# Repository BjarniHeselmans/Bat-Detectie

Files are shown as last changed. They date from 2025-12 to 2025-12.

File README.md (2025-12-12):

# Vleermuizen en Spouwmuren – ESPHome Sensor Node



## 1. Inleiding — Waarom bestaat dit project?

Dit project maakt deel uit van het BatSense-onderzoek rond vleermuizen en spouwmuren binnen de opleiding Elektronica-ICT aan Hogeschool PXL.  
Vleermuizen maken gebruik van spouwmuren als leef- en verplaatsingsruimte. Om dat gebruik beter te begrijpen, is betrouwbare monitoring van de omgevingscondities (zoals temperatuur en luchtvochtigheid) in die spouwmuren nodig.

Binnen het grotere BatSenseEmbedded-project werken meerdere deelteams samen aan een modulair systeem met verschillende nodes en een centrale verwerking.  
Deze repository focust op één specifieke node: een compacte, batterijgevoede sensormodule op basis van een ESP32-S2 (S2 Mini) en ESPHome, die via Wi‑Fi meetdata uit de spouwmuur doorstuurt naar het centrale systeem, gevormd door Home assistant.

---

## 2. Doelstelling — Wat moest er op het einde werken?

Het doel van dit deelproject is een werkende, reproduceerbare sensor node op te leveren die:

- temperatuur en relatieve luchtvochtigheid in een spouwmuur kan meten met een SHT30/SHT3X-sensor;
- autonoom op batterij kan functioneren, met deep-sleep om energie te besparen;
- via ESPHome elke sensor logisch aan de ESP32-S2 koppelt;
- de gemeten waarden via Wi‑Fi doorstuurt naar een centraal systeem (bv. Home Assistant of een backend uit BatSenseEmbedded);
- voldoende gedocumenteerd is (hardware + firmware) zodat een andere student de node opnieuw kan bouwen en integreren in het BatSense-systeem.
- De node moet aantoonbaar meetdata leveren die in het centrale systeem zichtbaar en logbaar is.

---

## 3. Materialen & Methoden — Hoe is het gebouwd?

### 3.1 Hardware

De sensor node bestaat uit:

- **Microcontroller:**  
  ESP32-S2 Mini (S2 Mini) met geïntegreerde Wi‑Fi.
- **Sensor:**  
  SHT30/SHT3X voor temperatuur- en relatieve luchtvochtigheid (I²C-communicatie).
- **Voeding:**  
  PowerBoost 500 Charger voor batterijvoeding en laadfunctionaliteit.
- **Overige:**  
  Bekabeling, connectoren en een behuizing/opstelling geschikt voor plaatsing in een spouwmuur.

- **[Research.md](./Docs/Research.md)** – hardwareopzet en keuzes
- **[board_controle.md](./Docs/Board_controle.md)** – basiscontroles van de S2 Mini
- **[sensor_kabels.md](./Docs/SensorKabels.md)** – sensorbekabeling en aanpassingen
- **[s2mini_flashen.md](./Docs/S2mini_flashen.md)** – stappen om de S2 Mini te flashen met ESPHome

De bekabeling, pinout en fysieke opstelling worden beschreven in de documenten in **[Docs/](./Docs/)**:

### 3.2 Firmware & Software (ESPHome & Home Assistant)

De volledige firmware op de sensornodes wordt opgebouwd met **ESPHome** en gekoppeld aan **Home Assistant** als centraal verwerkings- en visualisatieplatform.  
Belangrijkste elementen:

- **Configuratiebestand (ESPHome):**  
  [Scripts/base.yaml](./Scripts/base.yaml)
- **Sensorconfiguratie:**  
  Declaratie van de SHT3X-sensor via I²C, inclusief meetfrequentie.
- **Energiebeheer:**  
  Deep-sleep-configuratie om de node slechts periodiek te laten meten en verzenden.
- **Wi-Fi-configuratie:**  
  In `base.yaml` worden SSID en wachtwoord ingesteld zodat de node automatisch verbinding maakt met het netwerk.
- **Datadoorsturing:**  
  ESPHome publiceert de meetwaarden als netwerkentiteiten.
- **Home Assistant-integratie:**  
  Home Assistant detecteert de ESPHome-nodes automatisch, registreert alle sensoren als entiteiten, logt de meetwaarden continu en visualiseert deze via dashboards en grafieken.
- **Dataopslag & historiek:**  
  Meetdata blijft persistent bewaard in Home Assistant en blijft beschikbaar na een herstart.

### 3.3 Architectuur en datastroom

De datastroom voor deze node verloopt als volgt:

1. De node wordt gevoed door de batterij via de PowerBoost 500 Charger.
2. De ESP32-S2 wordt wakker uit deep-sleep.
3. ESPHome leest de SHT30/SHT3X-sensor uit via I²C (temperatuur en luchtvochtigheid).
4. De ESP32-S2 maakt verbinding met het Wi‑Fi-netwerk.
5. ESPHome stuurt de gemeten waarden via Wi‑Fi naar het centrale systeem (bv. Home Assistant of een server binnen BatSenseEmbedded).
6. Home Assistant ontvangt de data, slaat deze persistent op, en visualiseert de meetwaarden via dashboards en grafieken.
7. De data kan vanuit Home Assistant verder worden geëxporteerd (CSV/Excel).

Deze node is daarmee één van de sensoren in het grotere BatSenseEmbedded-ecosysteem, waar meerdere nodes en servers samenwerken.

---

## 4. Resultaten — Wat werkt effectief?

De volgende resultaten werden bereikt met deze sensor node:

- **Werkende hardwaremodule:**  
  De combinatie van S2 Mini, PowerBoost 500 Charger en SHT30/SHT3X levert een stabiel systeem op dat in een spouwmuur kan geplaatst worden.
- **Stabiele omgevingsmetingen:**  
  Temperatuur- en vochtigheidswaarden worden betrouwbaar uitgelezen via ESPHome.
- **Wi‑Fi-communicatie:**  
  De node maakt verbinding met het geconfigureerde Wi‑Fi-netwerk en publiceert de sensorwaarden als entiteiten.
- **Integratie met centraal systeem:**  
  De data kan worden ingelezen en gelogd door een hoger niveau platform (bijvoorbeeld Home Assistant of een centrale server binnen BatSenseEmbedded).

Het aantal werkende modules, testduur en stabiliteitstesten hangen af van de concrete metingen en opstellingen die in de loop van het project zijn uitgevoerd. Deze kunnen aangevuld worden met grafieken, logs en screenshots in de documentatie en in de centrale projectrapportage.

---

## 5. Besluit — Wat hebben we geleerd?

Uit dit deelproject rond de ESPHome sensor node kwamen de volgende inzichten naar voren:

- **Energiebeheer is cruciaal:**  
  Deep-sleep en meetinterval hebben een grote impact op de batterijduur. Het juist instellen hiervan is essentieel voor langdurige metingen in spouwmuren.
- **Omgevingsinvloeden:**  
  Vocht en condensatie vormen een risico voor de hardware. Het ontwerp van de behuizing en de plaatsing van de sensor zijn belangrijk voor de betrouwbaarheid.
- **Wi‑Fi-bereik en stabiliteit:**  
  In of rond een spouwmuur is het Wi‑Fi-signaal niet altijd optimaal. Dit moet meegenomen worden in de plaatsing van nodes en de keuze van access points.
- **Modulariteit binnen BatSenseEmbedded:**  
  Door ESPHome te gebruiken en de node duidelijk te documenteren, kan deze sensor eenvoudig geïntegreerd worden in de centrale BatSenseEmbedded-architectuur en door andere studenten worden nagebouwd of uitgebreid.

Deze node levert zo een concrete, technische bouwsteen voor het bredere vleermuis- en spouwmurenonderzoek, en illustreert hoe een robuuste, batterijgevoede IoT-sensorknoop ontworpen en gedocumenteerd kan worden.

---

## Projectstructuur (overzicht)

Docs/
Research.md
01_board_controle.md
02_sensor_kabels.md
03_s2mini_flashen.md
Attachments/
... (screenshots en foto’s)

Scripts/
HTSensor.yaml

text

- **[Docs/](./Docs/)** bevat alle documentatie rond hardware, tests en opbouw.
- **[Scripts/](./Scripts)** bevat de ESPHome-configuratie waarmee de sensoren gekoppeld en via Wi‑Fi doorgestuurd worden.
- **[firmware/](./firmware/)** bevat dummy sensor logica.

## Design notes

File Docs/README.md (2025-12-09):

Deze map bevat alle documentatie die is opgesteld tijdens het **Bat Detectie**-project.  
Hieronder volgt een overzicht van de bestanden en hun inhoud.

---

## Documenten

### 1. [Research.md](./Research.md)
**Onderwerp:** Hardware overzicht en functionaliteit.  
**Inhoud:**  
- Beschrijving van de **S2 Mini**, **PowerBoost 500 Charger** en **SHT30-sensor**.  
- Functionele uitleg van voeding, opladen en datalogging.  
- Aansluitingen en pinout details.  
- Toepassingen, tips en referenties naar datasheets en documentatie.

---

### 2. [Board_controle.md](./Board_controle.md)
**Onderwerp:** Controle van de S2 Mini-boardjes.  
**Inhoud:**  
- Testen van de boardjes via **Arduino IDE** en seriële monitor.  
- Identificatie van werkende en defecte boardjes.  
- Nummering en registratie voor verdere verwerking.  
- Screenshot van de seriële monitoruitvoer: **[./Attachments/serial_monitor_output.png](./Attachments/serial_monitor_output.png)**.

---

### 3. [Sensor_kabels.md](./SensorKabels.md)
**Onderwerp:** Verkorten en aansluiten van SHT3X-sensorbekabeling.  
**Inhoud:**  
- Controle op schade en waterschade.  
- Verkorten van kabels tot 1 meter voor betrouwbare I²C-communicatie.  
- Correcte aansluiting volgens datasheet.  
- Foto van sensor met kabel: **[./Attachments/SensorCable.png](./Attachments/SensorCable.png)**.

---

### 4. [S2mini_flashen.md](./S2mini_flashen.md)
**Onderwerp:** Flashen van de S2 Mini met ESPHome.  
**Inhoud:**  
- Installatie van ESPHome via pip.  
- Flashen met `esphome run .` en testen via `esphome logs .`.  
- YAML-configuratie voor de sensor, Wi-Fi, deep sleep en logging.  
- Gemaakt in samenwerking met Alexander (junior onderzoeker).

---

### 5. [ErrorGuide.md](./ErrorGuide.md)
**Onderwerp:** Guide to fix the commen error to be unable to flash.  
**Inhoud:**  
- een step by step guide om de error te kunnen oplossen
- vervolgt met de mannier om de esp te flashen

---

### 6. [HWInstallationGuide.md](./HWInstallationGuide.md)
**Onderwerp:** Hardware assembly guide for the casing.  
**Inhoud:**  
- een step by step guide om de casing in elkaar te steken

---

## Bijlagen

- **Attachments/**  
  Bevat afbeeldingen ter ondersteuning van de documentatie:

---

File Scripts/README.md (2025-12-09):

# ESPHome Sensor Node – Gebruik en Flashen

Deze sectie legt uit hoe de ESPHome-configuratie voor de sensor node werkt
en hoe je de firmware flasht op de **S2 Mini (ESP32-S2)** binnen dit project.

---

## 1. Wat doet deze ESPHome-config?

De ESPHome-configuratie voor deze node zorgt ervoor dat de S2 Mini:

- verbinding maakt met Wi‑Fi;
- de **SHT30/SHT3X-sensor** via I²C uitleest;
- **temperatuur** en **luchtvochtigheid** als entiteiten beschikbaar maakt;
- (optioneel) **deep-sleep** gebruikt om batterij te besparen;
- OTA-updates en logging via ESPHome ondersteunt.

De belangrijkste configuratie staat in:

- `Scripts/device(NMR).yaml`

---

## 2. Bestanden en structuur

In deze repo:

- `Scripts/HTSensor.yaml`  
  ESPHome-configuratie voor de S2 Mini:
  - type bord (`esp32-s2` / S2 Mini)
  - Wi‑Fi-instellingen
  - SHT30/SHT3X-sensor (I²C)
  - logger, API, OTA, deep-sleep (indien geconfigureerd)

- `Docs/03_s2mini_flashen.md`  
  Stapsgewijze uitleg om de S2 Mini te flashen (achtergrond en screenshots).

---

## 3. Voorbereiding

1. **Benodigdheden**
   - S2 Mini (ESP32-S2)
   - SHT30/SHT3X-sensor correct aangesloten (zie `Docs/02_sensor_kabels.md`)
   - USB‑kabel naar je pc
   - Wi‑Fi-netwerk (SSID + wachtwoord)

2. **Software**
   - Python + `pip`
   - ESPHome installeren:
     ```
     pip install esphome
     ```
   - Optioneel: ESPHome Dashboard (via Home Assistant of standalone)

---

## 4. Wi‑Fi en sensorgegevens instellen

Open `Scripts/HTSensor.yaml` en controleer:

- **Wi‑Fi-instellingen**:
wifi:
ssid: "JOUW_SSID"
password: "JOUW_WACHTWOORD"

- **Sensorconfiguratie** (voorbeeld):
i2c:
sda: <GPIO_SDA>
scl: <GPIO_SCL>
scan: true

sensor:
- platform: sht3xd
temperature:
name: "Spouwmuur Temperature"
humidity:
name: "Spouwmuur Humidity"
address: 0x44
update_interval: 10s

Pas hier enkel aan wat in jouw opstelling afwijkt (SSID, wachtwoord, pinnen, namen).

---

## 5. Eerste keer flashen (via USB)

1. Verbind de S2 Mini via USB met je pc.
2. Ga in een terminal naar de projectmap:
cd Scripts

3. Flash de node met ESPHome:
esphome run HTSensor.yaml

4. Kies de juiste seriële poort wanneer ESPHome daarom vraagt.

ESPHome:
- compileert de firmware;
- uploadt ze naar de S2 Mini.

---

## 6. Logs bekijken en testen

Na het flashen kun je live logs bekijken:

esphome logs HTSensor.yaml

Controleer of:
- de node verbinding maakt met je Wi‑Fi;
- de SHT30/SHT3X-sensor waarden geeft;
- (indien ingesteld) deep-sleep correct werkt (node gaat slapen en wordt weer wakker).

---

## 7. OTA-updates (draadloos)

Na de eerste USB-flash kun je wijzigingen aan `HTSensor.yaml` draadloos uploaden:

esphome run HTSensor.yaml

ESPHome zoekt dan de node op je netwerk en doet een OTA-update.

---

## 8. Integratie in het BatSense-systeem

De sensoren die in `HTSensor.yaml` gedefinieerd zijn (bijv. `Spouwmuur Temperature`,
`Spouwmuur Humidity`) verschijnen als entiteiten in ESPHome / Home Assistant
of kunnen door de centrale BatSense-componenten uitgelezen worden volgens de
architectuur die in het teamproject is afgesproken.

---

## 9. Veelvoorkomende problemen

- **Node verschijnt niet op Wi‑Fi**  
  → Controleer SSID/wachtwoord in `HTSensor.yaml`.  
- **Geen sensorwaarden**  
  → Controleer I²C-pinnen en bekabeling (zie `Docs/02_sensor_kabels.md`).  
- **Geen logs**  
  → Controleer seriële poort of netwerk, probeer opnieuw:
    ```
    esphome logs HTSensor.yaml
    ```

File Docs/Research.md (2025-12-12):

# S2 Mini & PowerBoost 500 Charger & SHT30

Dit project combineert de **S2 Mini** microcontroller met de **Adafruit PowerBoost 500 Charger** en de **SHT30 temperatuur- en vochtigheidssensor** voor een compacte, draagbare oplossing die zowel voeding, opladen als omgevingsmeting ondersteunt.

## Componenten

- **S2 Mini**
  - ESP32-S2 gebaseerde microcontroller
  - Ondersteunt Wi-Fi
  - Klein formaat en laag energieverbruik

- **PowerBoost 500 Charger**
  - LiPo/Li-ion batterij lader
  - 5V boost converter tot max. 500mA
  - Micro-USB aansluiting voor opladen
  - Automatische overschakeling tussen USB- en batterijvoeding

- **SHT30**
  - Temperatuur- en luchtvochtigheidssensor
  - Meetbereik:
    - Temperatuur: -40 tot +125 °C (±0.2 °C nauwkeurigheid)
    - Vochtigheid: 0–100 %RH (±2 %RH nauwkeurigheid)
  - Communicatie via I²C
  - Lage stroomconsumptie, geschikt voor draagbare toepassingen

## Functionaliteit

- Voeding van de **S2 Mini** via een LiPo- of Li-ion batterij.
- Opladen van de batterij via micro-USB.
- 5V output van de PowerBoost voedt direct de S2 Mini.
- Metingen van temperatuur en luchtvochtigheid via de SHT30.
- Data kan via Wi-Fi worden doorgestuurd of lokaal verwerkt.
- Ideaal voor draagbare IoT-projecten en omgevingsmonitoring.

## Aansluitingen
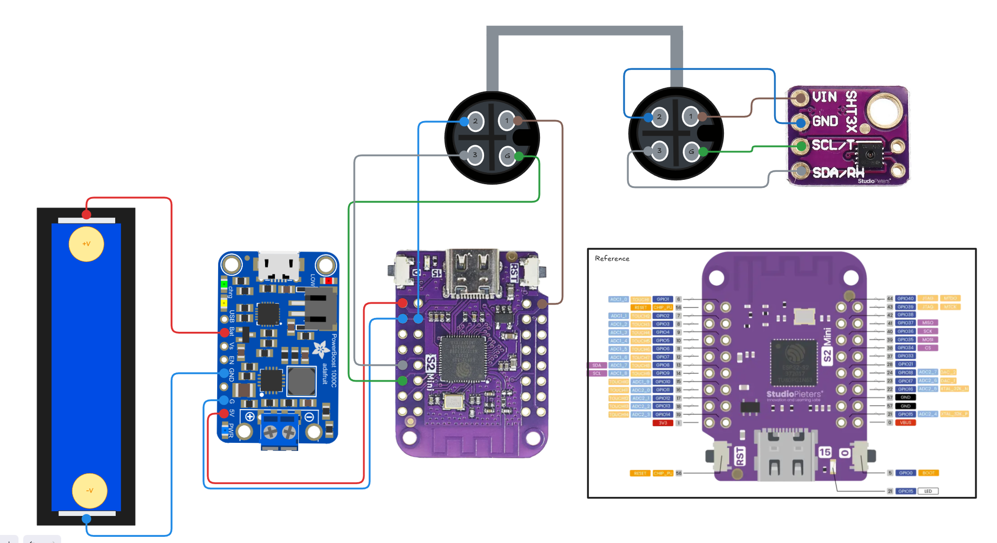
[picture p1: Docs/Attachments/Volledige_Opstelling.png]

1. **Batterij → PowerBoost**
   - Verbind een LiPo/Li-ion batterij met de JST-connector van de PowerBoost.

2. **PowerBoost → S2 Mini**
   - Sluit de **5V-uitgang** van de PowerBoost aan op de **5V/VBUS pin** van de S2 Mini.
   - Sluit **GND** van beide borden aan.

3. **SHT30 → S2 Mini**
   - **VCC** → 3.3V pin van de S2 Mini  
   - **GND** → GND van de S2 Mini  
   - **SDA** → GPIO 8 (SDA)  
   - **SCL** → GPIO 9 (SCL)  
   *(controleer de pinout van je S2 Mini, sommige boards gebruiken andere standaard I²C-pinnen)*

4. **Opladen**
   - Gebruik een micro-USB kabel op de PowerBoost om de batterij op te laden.
   - Het systeem kan tijdens het opladen blijven functioneren.

## Let op

- Zorg dat de aangesloten batterij correct gepolariseerd is (rode draad = +, zwarte draad = -).
- De PowerBoost levert max. 500mA; houd rekening met stroomverbruik van de S2 Mini, SHT30 en eventuele extra randapparatuur.
- De SHT30 werkt op 3.3V; sluit hem niet aan op 5V.
- Gebruik een geschikte LiPo- of Li-ion batterij (bij voorkeur ≥ 500mAh).

## Toepassingen

- Draagbare IoT-projecten
- Sensoren en datalogging
- Omgevingsmonitoring (temperatuur en luchtvochtigheid)
- Kleine robotica toepassingen
- Wearables

## Referenties

- [S2 Mini documentatie](https://www.wemos.cc/en/latest/s2/s2_mini.html)  
- [Adafruit PowerBoost 500 Charger](https://cdn-learn.adafruit.com/downloads/pdf/adafruit-powerboost-500-plus-charger.pdf)  
- [SHT30 Datasheet (Sensirion)](https://sensirion.com/media/documents/213E6A3B/63A5A569/Datasheet_SHT3x_DIS.pdf)
- [SHT3x module functionality(controllerstech)](https://controllerstech.com/interface-sht3x-with-arduino/)

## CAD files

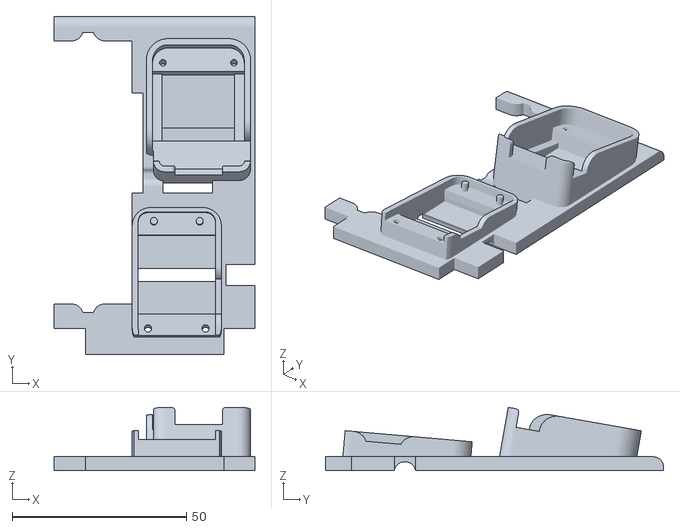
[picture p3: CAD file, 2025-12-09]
Docs/3D models/ScrewholderOBJ.obj
57.7 x 97.0 x 18.2

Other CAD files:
Docs/3D models/ScrewholderSTL.stl
Docs/3D models/Screwholder.3mf

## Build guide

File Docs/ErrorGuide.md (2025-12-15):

# ESPHome Installatiegids (zonder dependency-conflicten)

Deze handleiding legt uit hoe je ESPHome correct installeert in een aparte virtuele Python-omgeving zodat er geen conflicten ontstaan met andere pakketten zoals *mediapipe*.

---

## Waarom een virtuele omgeving?
Sommige pakketten vereisen **protobuf 4.x**, terwijl ESPHome **protobuf 5+** nodig heeft. Dit botst in één Python-installatie.  
Een virtuele omgeving voorkomt deze problemen.

---

# ESPHome installeren in een virtuele omgeving

## 1. Virtuele omgeving aanmaken
Maak een aparte map met een eigen Python-omgeving:

```bash
python -m venv esphome-env
```

---

## 2. Virtuele omgeving activeren

### **Windows**
```bash
esphome-env\Scripts\activate
```

Wanneer actief verschijnt `(esphome-env)` vóór je command prompt.

---

## 3. ESPHome installeren
Installeer ESPHome binnen deze omgeving:

```bash
pip install esphome
```

ESPHome kiest automatisch een geschikte protobuf-versie (5.x of 6.x).

---

# Projectstructuur

Plaats je ESPHome-configuratie (YAML-bestanden) in een normale gebruikersmap, bijvoorbeeld:

```
C:\Users\JouwNaam\Documents\ESPHome\
```

Ga daarna naar die map:

```bash
cd C:\Users\JouwNaam\Documents\ESPHome
```

---

# ESPHome gebruiken

## Firmware compileren en uploaden

```bash
esphome run device1.yaml
```

## Live logs bekijken

```bash
esphome log device1.yaml
```

---

# Verrificatie dat de sensor is geupload:



---

# Aanbevolen werkwijze

Gebruik **altijd** een virtuele omgeving voor ESPHome om dependency-conflicten te vermijden.

---

Veel succes!

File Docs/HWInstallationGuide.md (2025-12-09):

# Bottomcase install

## Step 1

Firstly be sure to check if all the required parts are found like in the image below. You should have 2 tiny screws for the ESP32, the 3D print to hold the parts, the lithium battery holder+battery management system+ESP32, another set of screws for the bms and finally the 4 big ones to screw in the lid to the enclosure.

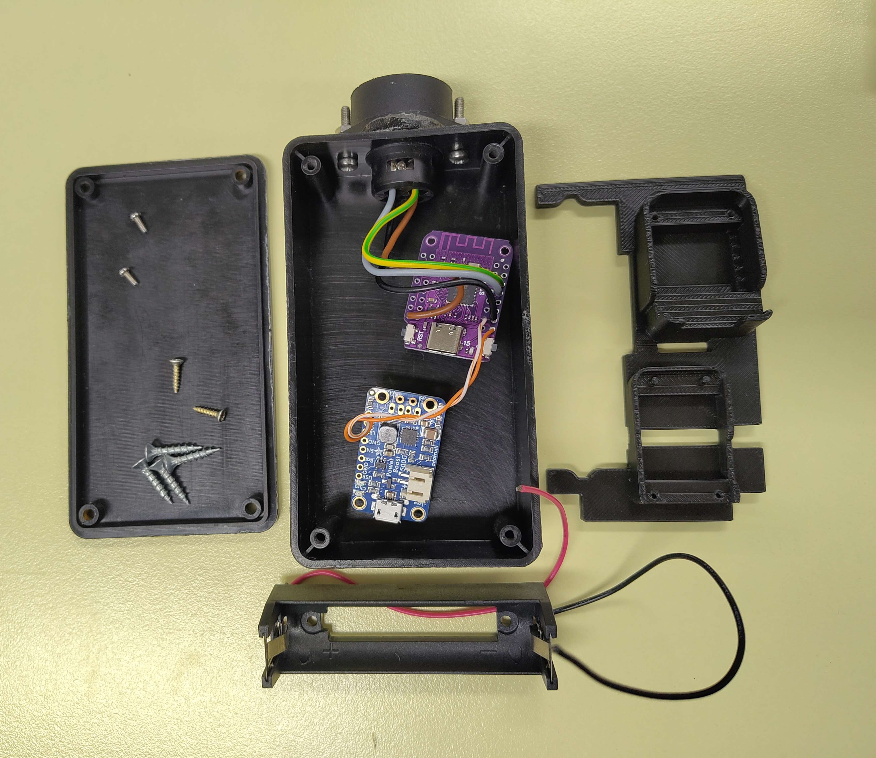
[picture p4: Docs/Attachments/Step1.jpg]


## Step 2

Now that you have confirmed that all components are included be sure to safely insert the battery holder inside of the 3D printed screwholder since it will be easier to mount it inside of the enclose this way.

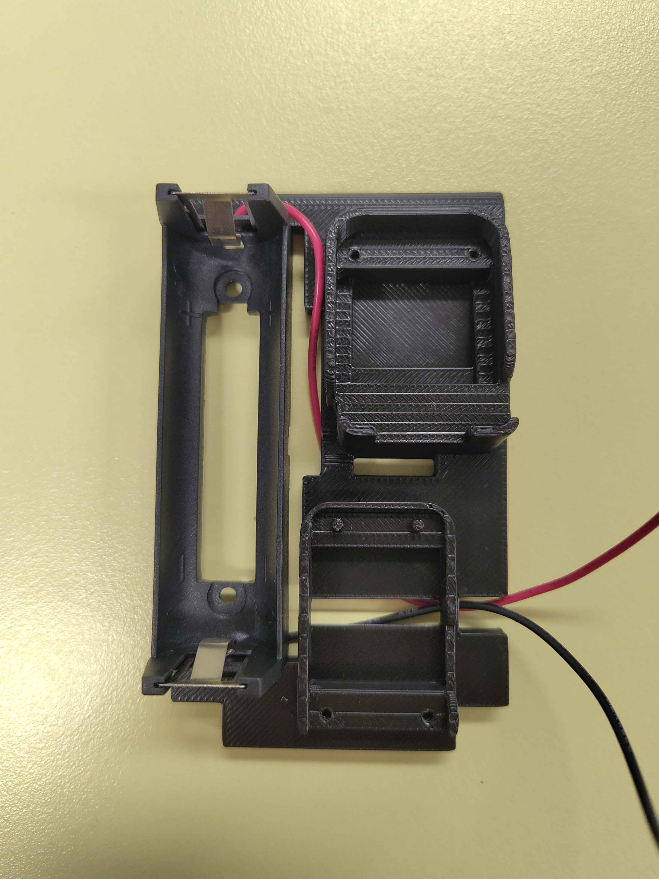
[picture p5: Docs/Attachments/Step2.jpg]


## Step 3

After that is done the screwholder can be safely slotted in making sure that the curved side is aimed to the top and that it looks like the image below. Then you can use the 4 tiny included screws to screw in the esp and the BMS system into the enclosure.

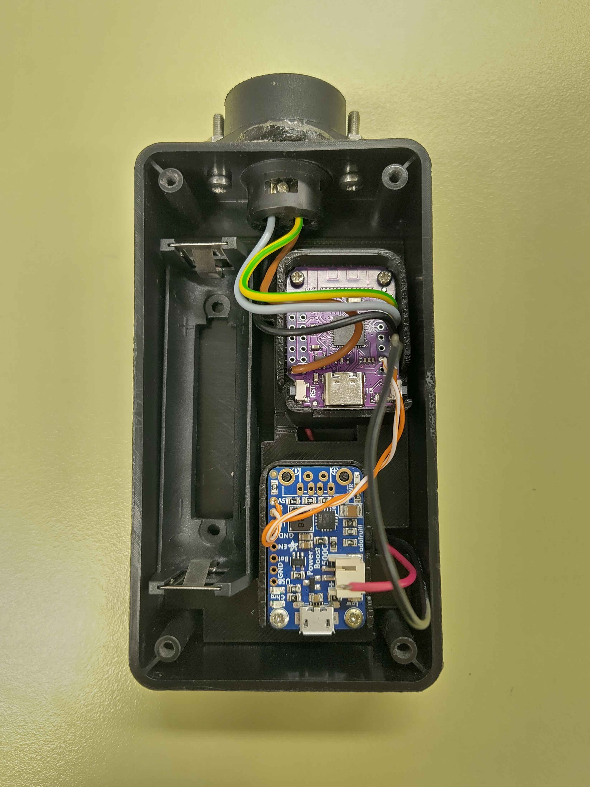
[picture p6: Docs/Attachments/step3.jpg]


## Step 4

Next the battery can be slotted into the enclosure making sure that the polarity is correct. This can be checked by aligning the + and minus sign as shown in the image below.

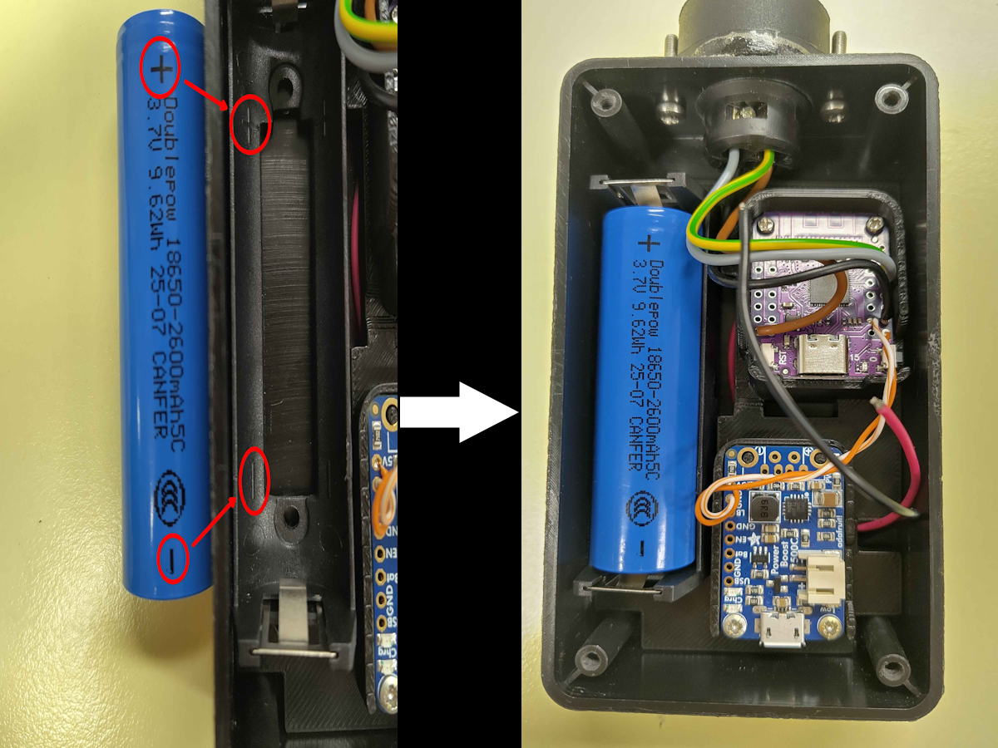
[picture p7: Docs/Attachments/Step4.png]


# Step 5

Now that everything for inside the case is installed the lid can be placed on top and screwed in with the biggest 4 screws the sensor kit is now fully assembled!

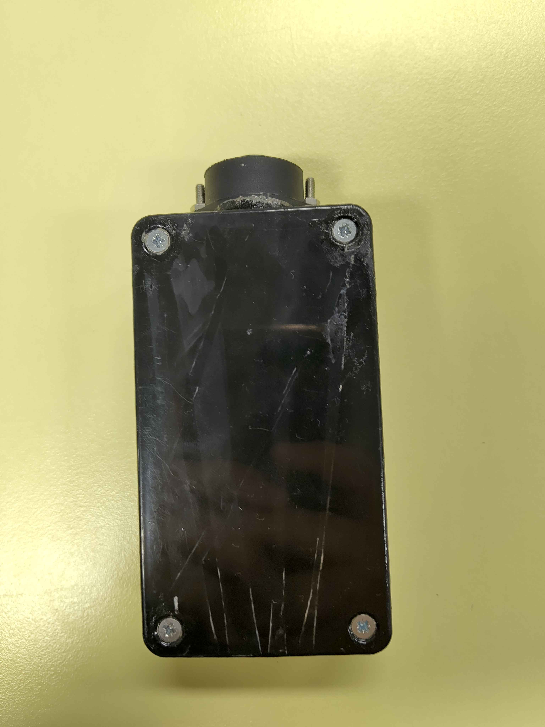
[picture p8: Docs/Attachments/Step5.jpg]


# Final note

Inside the resources folder multiple sets of files can be found. An [OBJ](/3D%20models/ScrewholderOBJ.obj), [STL](/3D%20models/ScrewholderSTL.stl), and a [3MF](/3D%20models/Screwholder.3mf). As a team the recommended one for printing is the 3MF it is currently set up to print properly for the Bambulab X1C. This will simply need to be delivered
to someone who owns any printer (does not need to be a Bambulab) and then
printed with ease.

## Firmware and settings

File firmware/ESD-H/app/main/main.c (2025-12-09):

/* Hello World Example

   This example code is in the Public Domain (or CC0 licensed, at your option.)

   Unless required by applicable law or agreed to in writing, this
   software is distributed on an "AS IS" BASIS, WITHOUT WARRANTIES OR
   CONDITIONS OF ANY KIND, either express or implied.
*/
#include "wifiAP.h"

void app_main()
{
    wifi_init();
    Server_init();
    ls_spiffs("/spiffs");
    file_test();
    fs_deinit();
}

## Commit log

2025-12-09 Revise README with project details and instructions
    Updated the README to include detailed project information, objectives, methodologies, and installation instructions for the embedded sensor module monitoring bat activity and environmental condition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
2025-12-09 Revise README for sensor node project details
    Updated the README to provide detailed information about the sensor node project, including its context, objectives, hardware overview, firmware, and installation instructions.
2025-12-09 Implemented sammy's repo
    [Screwholder.3mf, ScrewholderOBJ.obj, ScrewholderSTL.stl]
2025-12-09 Fix image link case in HWInstallationGuide.md
    Updated image source in Step 3 to use lowercase filename.
2025-12-09 added oliwier his work
    [partitions.csv]
2025-12-09 Update README with new device configuration file
2025-12-15 Update ErrorGuide with sensor verification images
    Removed optional protobuf installation instructions and added verification images for sensor upload.
2025-12-16 Added the elektrical schematic
